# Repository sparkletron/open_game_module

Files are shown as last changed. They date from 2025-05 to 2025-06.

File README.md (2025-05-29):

# Open Game Module
### Schematic, PCB, and CPLD design.



---

  author: Jay Convertino

  date: 2025.05.21

  details: Open Game Module Expansion for the Coleocvision that is Super Game Module compatible.

  license: MIT

---

## LICENSE
  - All files related to or generated from the KiCAD source fall under the MIT license.
  - All files related to or generated from the Verilog source fall under the MIT license.
  - All files generated by me, Jay Convertino, fall under the MIT license.
  - All files from other sources fall under the license of their specification.

## RELEASE VERSIONS
### Current
  - 1.0.0 - First working version

### Past
  - DEV

## Intro
  This is a open source version of the Super Game Module. This uses a CPLD for the glue logic.

## Documentation
  For detailed usage information, please navigate to one of the following sources. They are the same, just in a different format.
  - [open_game_module.pdf](docs/manual/open_game_module.pdf)
  - [github page](https://sparkletron.github.io/open_game_module/)

## SOFTWARE REQUIREMENTS
  - KiCAD v8.X
  - Quartus v13.0.1sp1 web edition
  - Altera USB Blaster

## BUILD TIPS
  This design is made so anyone can build this. Though it will need a board from a PCB manufacture due to the small pitch and
  vias. There are only a few SMD devices, the CPLD, and a few resistors. These are larger to help make soldering easier.

  Recommend populating the SMD parts first, then moving on to the through hole parts from passive to active.

  All case parts are ABS Plastic.

## Completed Project Image

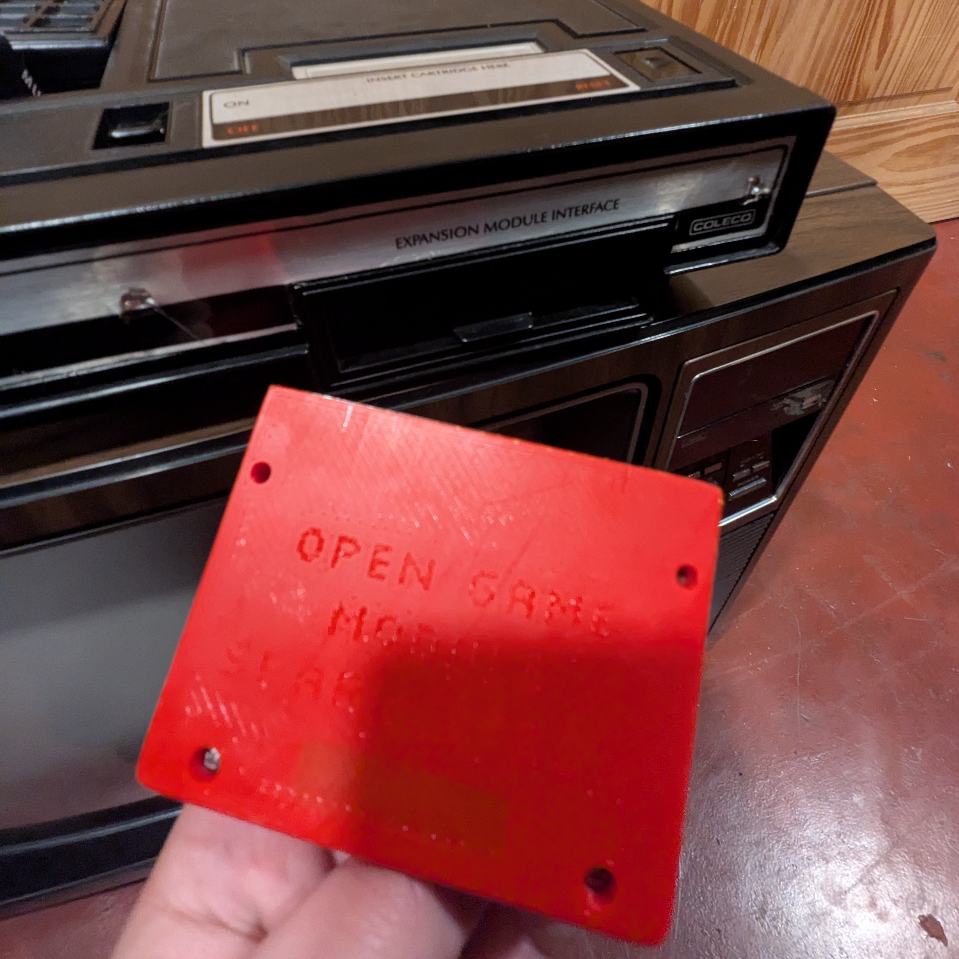
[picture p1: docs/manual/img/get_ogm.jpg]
ogm|300


## PCB IMAGE

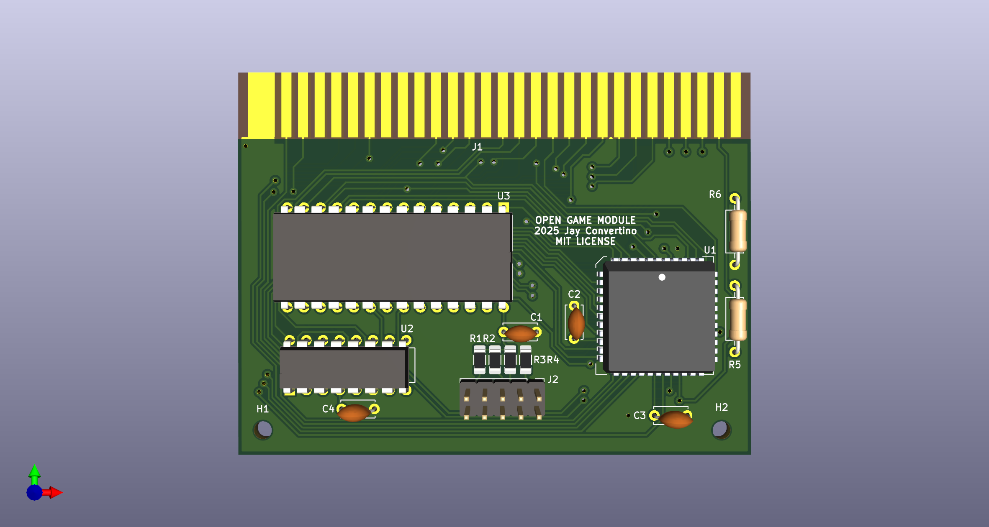
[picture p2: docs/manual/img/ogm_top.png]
pcb_3D_img_front|300


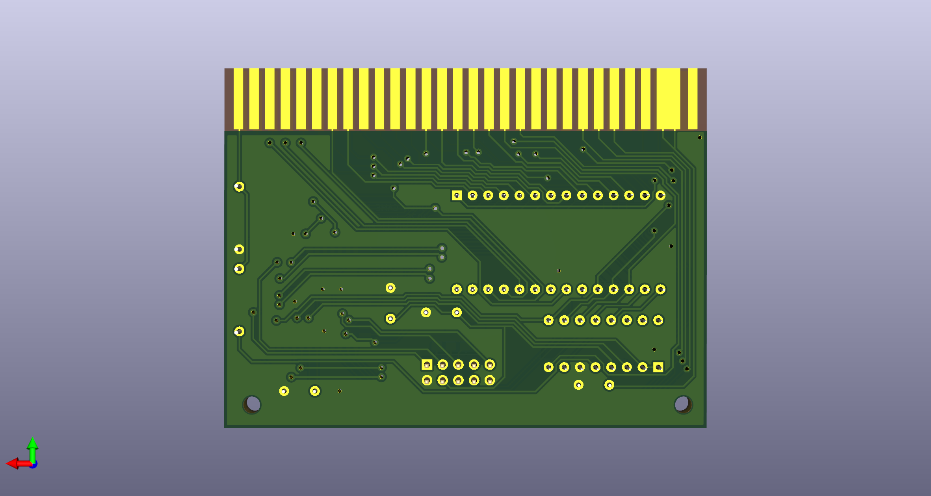
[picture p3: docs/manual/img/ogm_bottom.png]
pcb_3D_img_back|300


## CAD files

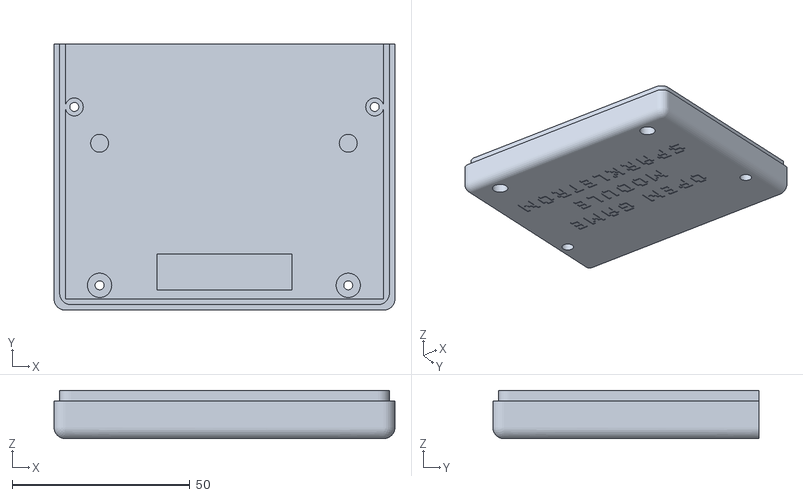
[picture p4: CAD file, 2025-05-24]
models/3D_print/top.stl
96.0 x 75.0 x 13.6

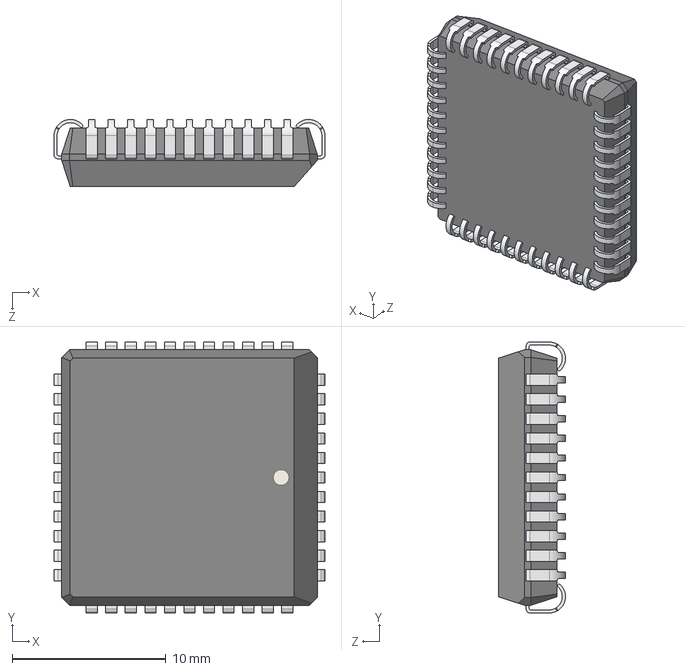
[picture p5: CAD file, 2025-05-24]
schematic/model/User Library-PLCC44-1.STEP
17.6 x 17.6 x 4.36 mm

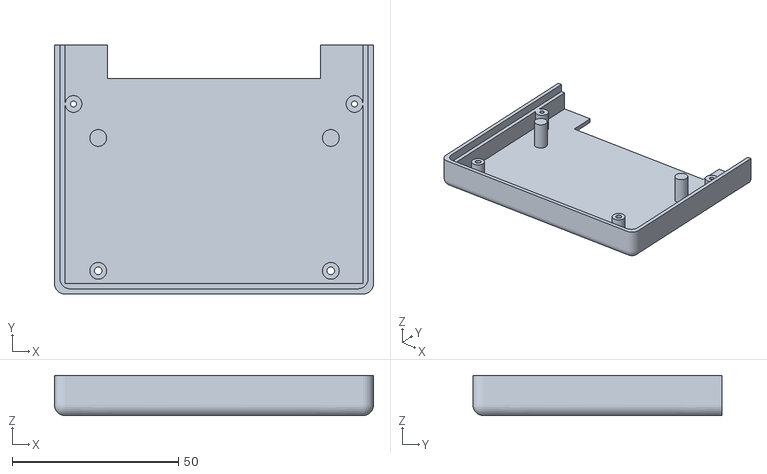
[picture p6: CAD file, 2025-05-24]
models/3D_print/bottom.stl
96.0 x 75.0 x 12.1

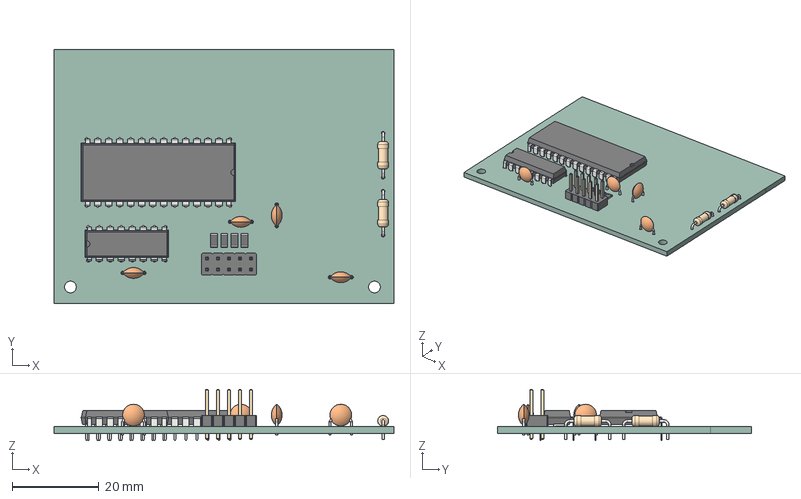
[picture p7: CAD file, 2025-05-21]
schematic/model/open_game_module.step
78.3 x 58.4 x 11.8 mm
PinHeader_2x05_P254mm_Vertical
C_Disc_D50mm_W25mm_P500mm x 4
R_1206_3216Metric x 4
DIP-28_W15.24mm
DIP-16_W7.62mm
R_Axial_DIN0207_L63mm_D25mm_P1016mm_Horizontal x 2
open_game_module_PCB

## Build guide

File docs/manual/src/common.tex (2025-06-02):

\begin{titlepage}
  \begin{center}

  {\Huge Open Game Module}

  \vspace{25mm}

  

  \vspace{25mm}

  \today

  \vspace{15mm}

  {\Large Jay Convertino}

  \end{center}
\end{titlepage}

\tableofcontents

\newpage

\section{Introduction}

\par
Open Game Module (OGM) is a open source expansion card for the Colecovision. This module is Super Game Module (SGM) compatable.
This means all SGM games will run when this module is used with a Colecovision. The sound is expanded with a Yamaha YMZ284
instead of the GI AY chip.

\subsection{Specifications}

\par
\begin{itemize}
  \item 32KiB of RAM
  \item YMZ284 Sound Chip
  \item MAX7000S CPLD (EPM7064SLC)
  \item PCB, two layer
\end{itemize}

\subsection{Parts List}

\subsubsection{electronics}
\begin{footnotesize}
\begin{longtable}{ |*{4}{c|} }
\hline
{Item} & {Qty} & {Reference(s)} & {Value} \\
\hline
{1} & {1} & {J1} & {Connector, 60 pin} \\
\hline
{2} & {4} & {C1, C2, C3, C4} & {100pF} \\
\hline
{3} & {1} & {U1} & {EPM7064SLC-10} \\
\hline
{4} & {1} & {U2} & {YMZ284} \\
\hline
{5} & {1} & {U3} & {HM62256BLP} \\
\hline
{6} & {1} & {R5} & {2k2} \\
\hline
{7} & {1} & {R6} & {4k7} \\
\hline
{8} & {4} & {R1, R2, R3, R4} & {1k} \\
\hline
{9} & {1} & {J2} & {Pin Header, 10 pin} \\
\hline
\end{longtable}
\end{footnotesize}

\subsubsection{hardware}
\begin{footnotesize}
\begin{longtable}{ |*{4}{c|} }
\hline
{Item} & {Qty} & {Reference(s)} & {Value} \\
\hline
{1} & {2} & {S1} & {\#2-32 x 1/4 Fastenal 0148209, screw} \\
\hline
{1} & {2} & {S2} & {\#4-40 x 1/2 Fastenal 0173613, screw} \\
\hline
{2} & {1} & {TOP} & {top.stl 100.00} \\
\hline
{3} & {1} & {BOTTOM} & {bottom.stl 100.00} \\
\hline
\end{longtable}
\end{footnotesize}

\section{Building}

\par
This document assumes some Electrical Engineering knowledge. Building circuits is not
trivial due to the mix of SMD and through hole components. What follow are general
steps to build the OGM.

\begin{itemize}
  \item Create PCB from schematic/gerber/open\_game\_module.zip
  \item Populate PCB
  \item Power up and program CPLD
  \item 3D print case
  \item Assemble OGM circuit board and case.
\end{itemize}

\subsection{Directory Guide}

\par
Below highlights important folders from the root of the OGM.

\begin{enumerate}
  \item \textbf{docs} Contains all documentation related to this project.
    \begin{itemize}
      \item \textbf{datasheets} Contains all datasheets for components.
      \item \textbf{manual} Contains user manual and github page that are generated from the latex sources.
      \item \textbf{schematic} PDF of the KiCAD schematic.
    \end{itemize}
  \item \textbf{schematic} KiCAD v8.X schematic and PCB designs
    \begin{itemize}
      \item \textbf{gerber} Contains gerber files and archives for production.
    \end{itemize}
  \item \textbf{src} CPLD bitstream source
    \begin{itemize}
      \item \textbf{open\_game\_module} Contains verilog source code and constraits
      \item \textbf{quartus13sp01} Quartus project used to generate bitstream. POF file located here.
    \end{itemize}
\end{enumerate}

\subsection{Dependencies}

\par
The following are the dependencies needed to build the bitstream and PCB for the system.

\begin{itemize}
  \item Quartus 13.0 sp1
  \item python 3.X
  \item KiCAD v8.X
\end{itemize}

\input{src/fusesoc/files_fusesoc.tex}

\subsubsection{Fusesoc}
\par
Fusesoc is used for the simulation target only. There are no build targets due to the use of Quartus 13.0sp1.
This makes the use of it a bit silly. It does make it easier to use in future projects where the RAM,ROM,CPU,VDP,
and Sound chips are also IP cores.

\input{src/fusesoc/targets_fusesoc.tex}

\subsubsection{Quartus}
\par
This project uses the last version of Quartus that supports the MAX7000S series. The version is 13.0sp1.
The project is located at src/quartus13sp01/. Once you have the project open please follow the softwares steps
for building and programming the CPLD bitstream.

\subsection{PCB}

\par
The top has all the components of the circuit. The bottom contains none. This is a simple two layer board with a card edge. The card edge must have the pins of the socket bent to make contact and be soldered to it. The right angle connector is double the cost of the vertical one. Plus these are easier to obtain.

\begin{figure}[h!]
\caption{Top}
\centering

\end{figure}

\begin{figure}[h!]
\caption{Bottom}
\centering

\end{figure}

\subsection{3D Printed Case}

\par
The 3D printed case has been tested on two different printers. It has only been tested with ABS filament.
The parts list for the 3D printed case has the STL file name in the value and the XXX.X value is the scale size.
In general I recommend the following steps for assembly.

\begin{enumerate}
  \item Bottom, sit pcb aligned to screw holes.
  \item Top, sit top half on top and install screws.
\end{enumerate}

\subsection{CPLD Programming}

\par
There is one device that need to be programmed which is the CPLD (complex programmable logic device).
This is programmed with quartus using the JTAG header to upload the bitfile.
\par
Quartus 13.0sp1 is the easiest way to build and program the MAX7000 CPLD. You will need an altera blaster.
I recommend the chinese clone blasters, they actually worked the best. While the worst was the Terasic blaster
which did not work at all. As for instructions on how to program it in Quartus, please see the software for details.

\newpage

\section{Usage}

\subsection{Console}
\par
The expansion module must be firmly inserted into the expansion connector of the Colecovision while it is powered off. If you have issues, be sure to clean the Colecovision expansion connector and reinsert the cart. It is recommened to push the cart in as straght as possible.

\begin{enumerate}
  \item \textbf{Get OGM} \par 
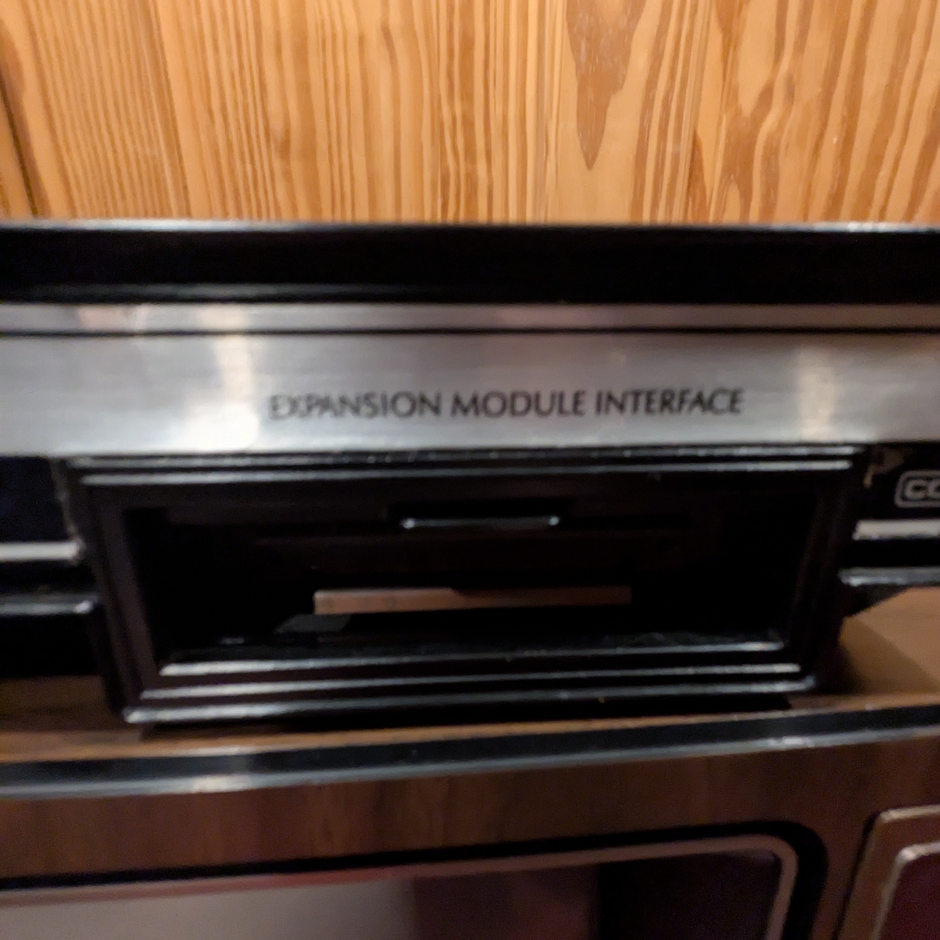
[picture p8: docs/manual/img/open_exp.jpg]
  \item \textbf{Open Expansion Cover} \par 
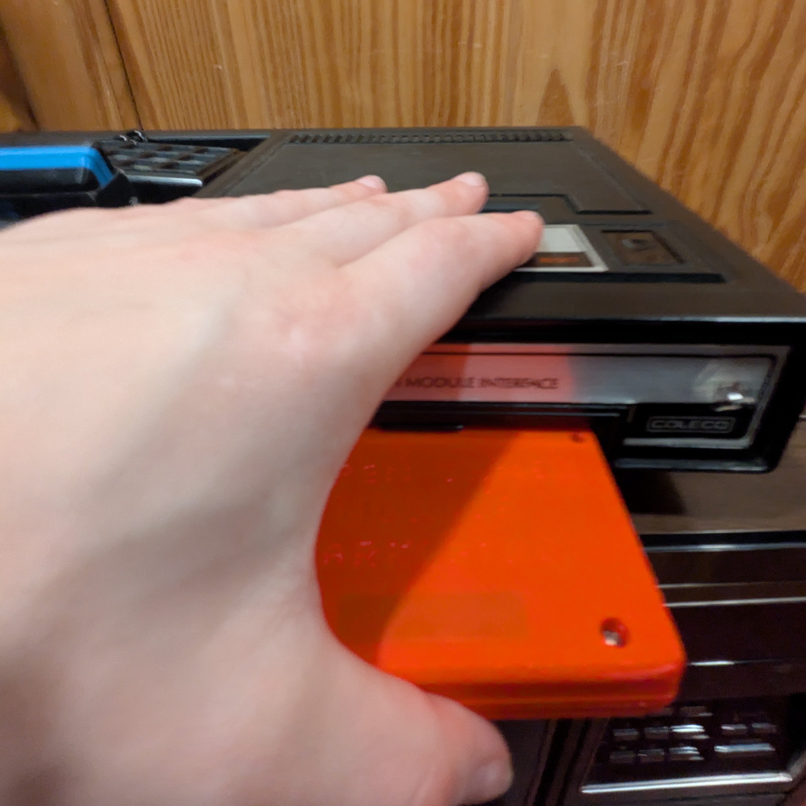
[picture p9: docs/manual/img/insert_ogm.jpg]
  \item \textbf{Insert Open Game Module} \par 
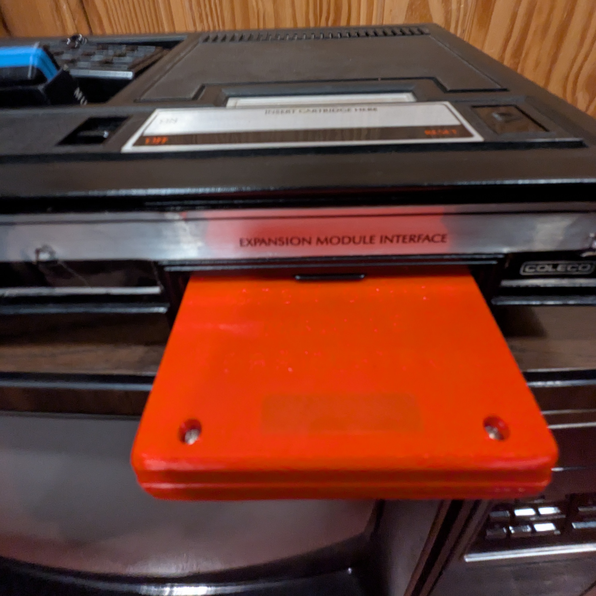
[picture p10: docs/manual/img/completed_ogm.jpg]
  \item \textbf{Completed} \par 
\end{enumerate}

\subsection{Software Programming}
\par
Module Documentation has in\-depth details for using the OGM register bits. You could do this in many different ways, but
having the SDCC compiler know ahead of time that the RAM is there works well for me. There are different stragies that could be done for this
but I feel this is the simplest way. Other methods can provide better detection of the OGM. The psudo code steps are as follows.

\begin{enumerate}
  \item Setup expansion RAM, (NOTE COULD CHECK IF REGISTER VALUE IS EQUAL TO THE DEFAULT TO VERIFY SGM)
  \item Setup IRQS
  \item Copy IRQs to RAM where ROM jumps used to be.
  \item Setup Sound CHIP, (READ BACK TO CHECK EXISTANCE)
\end{enumerate}

\subsubsection{Assembly Code For RAM Init}

\par
This brief assembly code doesn't actually check for the SGM it simply enables the ram registers, sets the irqs, and starts main. This code is taken
from RODAC and isn't complete, see RODAC coleco\_sgm arch crt0.s for complete code.

\begin{lstlisting}[language={[x86masm]Assembler}]
_SGM_RAM_ENA_PORT     .equ 0x0053
_SGM_BIOS_SWAP_PORT   .equ 0x007F
_NMI_SIZE             .equ (_irq_nmi_end - _irq_nmi + 1)
_SPIN_SIZE            .equ (_irq_spin_end - _irq_spin + 1)
;setup for super game module.
ld a,#0x01
out (_SGM_RAM_ENA_PORT), a
ld a,#0x0D
out (_SGM_BIOS_SWAP_PORT), a
;setup ram locations with irq vectors?, 0x8 etc.
;reti
ld a,#0xED
ld (0x08),a
ld (0x10),a
ld (0x18),a
ld (0x20),a
ld (0x28),a
ld (0x30),a
ld a,#0x4D
ld (0x09),a
ld (0x11),a
ld (0x19),a
ld (0x21),a
ld (0x29),a
ld (0x31),a
;copy code to ram
;nmi first
ld bc, #_NMI_SIZE
ld hl, #_irq_nmi
ld de, #0x0066
ldir
;spin
ld bc, #_SPIN_SIZE
ld hl, #_irq_spin
ld de, #0x0038
ldir
ld	sp, #0x8000
call gsinit
call  _main
rst   0x0
\end{lstlisting}

\subsubsection{C Code for SDCC}

\par
The code below is based on using SDCC 4.X.X as the C complier with a custom crt0.s. Essentially for the sound chip you
need to communicate with it by writing an address to it to use, then the data. You can also read from the it to
verify the chip exists and that the OGM is working. Though for the OGM its chip does not have a read function. It is
emulated for registers 0, 2, and 4 (0=1, 2=3, and 4=5) in the CPLD so all opcode/team pixelboy games will startup correctly.

\begin{lstlisting}[language=C]

#define GI_SND_CP_ADDR    0x50
#define GI_SND_WDATA_ADDR 0x51
#define GI_SND_RDATA_ADDR 0x52

__sfr __at(GI_SND_CP_ADDR)    GI_SND_CP_PORT;
__sfr __at(GI_SND_WDATA_ADDR) GI_SND_WDATA_PORT;
__sfr __at(GI_SND_RDATA_ADDR) GI_SND_RDATA_PORT;

/*** send address to chip ***/
inline void sendAddr(uint8_t addr)
{
  di();

  GI_SND_CP_PORT = addr;

  ei();
}

/*** send data to chip ***/
inline void sendData(uint8_t data)
{
  di();

  GI_SND_WDATA_PORT = data;

  ei();
}

/*** send data to chip ***/
inline void readData(uint8_t data)
{
  di();

  data = GI_SND_RDATA_PORT;

  ei();
}
\end{lstlisting}

\section{Architecture}

\par
The OGM architecture emulates the Super Game Module. This is done with a CPLD which performs the RAM (32KiB) and sound (YMZ284) selects. It also caches the the sound writes for later reads. For the RAM selects this is done by emulating the original 74LS138 decoders. This is used to disable the internal RAM with the register at 0x53 by writing one to bit zero. This will remove the internal 1KiB and extend the console to 24KiB. Then to swap out the ROM for RAM for an additional 8KiB the register 0x7F has a zero written to bit one (default value for the register is 0x0F). For the sound, all writes to register 7 and lower have an address cache to store the last address requested. This is due to the architecture of the original chip where the address is selected and then a read is performed. With the address set a subset of the register addresses are mapped to cache registers on the CPLD. See the section after this one for the mapping. This allows the cheaper YMZ284 to be used for sound generation. There are two resistors used to pad the output of the YMZ284 for acceptable levels when mixed with the original in the console. The console internally has a DC blocking capacitor, so no additional capacitors are needed.

\subsection{Fix for opcode games}

Opcode super game module mega cart games have a particular check for the sound chip in there startup routine.

\begin{enumerate}
  \item Set AY register address to 0x00
  \item Write the value 0xAA to AY (register 0x00).
  \item Set AY register address to 0x02
  \item Write the value 0x55 to AY (register 0x02).
  \item Set AY register address to 0x00
  \item Read the value from AY (register 0x00).
  \item Compare to value originally written (0xAA), fail if not matching
  \item Set AY register address to 0x02
  \item Read the value from AY (register 0x02).
  \item Compare to value originally written (0x55), fail if not matching.
\end{enumerate}

The hack fix for my setup is to only have 4 8 bit regiters for 0,1,2,3,4,5,6, and 7. The mapping is
AY Software Register ADDRESS => Cache Register ADDRESS

\begin{itemize}
  \item 0 => 0
  \item 1 => 0
  \item 2 => 1
  \item 3 => 1
  \item 4 => 2
  \item 5 => 2
  \item 6 => 3
  \item 7 => 3
\end{itemize}

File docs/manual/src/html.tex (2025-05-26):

\documentclass{article}
\usepackage{graphicx}
\usepackage{listings}
\usepackage{longtable}
\usepackage[hidelinks]{hyperref}
\begin{document}

  \include{src/common.tex}

  \section{Module Documentation}

  \subsection{\href{../files/open_game_module-v.html}{Open Game Module}}

  \section{Schematics}

  \subsection{\href{../../../schematic/open_game_module.pdf}{Open Game Module}}

\end{document}

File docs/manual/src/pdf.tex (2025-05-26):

\documentclass[usletter]{article}
\usepackage{DejaVuSans}
\renewcommand*\familydefault{\sfdefault}
\usepackage[T1]{fontenc}
\usepackage{graphicx}
\usepackage{listings}
\usepackage{pdfpages}
\usepackage{multirow}
\usepackage{lscape}
\usepackage{graphics}
\usepackage{longtable}
\usepackage{graphics}
\usepackage{lscape}
\usepackage[hidelinks]{hyperref}
\begin{document}

  \include{src/common.tex}

  \section{Code Documentation}
  \par
  This section documents the verilog code for the CPLD in detail.

  \includepdf[pages=-, addtotoc={1,subsection,1,Open Game Module,p1}, pagecommand={}]{open_game_module-v.pdf}

  \section{Drawings and Schematics}
  \par
  This section has CAD drawings and schematics.

  \includepdf[pages=-, addtotoc={1,subsection,1,Schematics,p1}, pagecommand={}]{../schematic/open_game_module.pdf}

\end{document}

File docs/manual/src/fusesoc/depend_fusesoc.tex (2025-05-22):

\subsubsection{Open Game Module Glue Depenecies}
\begin{itemize}
\end{itemize}

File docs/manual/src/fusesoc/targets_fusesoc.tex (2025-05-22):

\subsubsection{Open Game Module Glue Targets}
\begin{itemize}
\item default
	\begin{itemize}
	\item[$\space$] Info: Default IP target for future tool intergration.
	\item src
	\item constr
	\end{itemize}
\item sim
	\begin{itemize}
	\item[$\space$] Info: Simulation target for basic test bench.
	\item src
	\item tb
	\end{itemize}
\end{itemize}

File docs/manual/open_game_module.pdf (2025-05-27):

# Open Game Module

May 27, 2025

## Jay Convertino

## Contents

1 Introduction | 2
2 Building | 2
3 Usage | 7
4 Architecture | 9
5 Code Documentation | 11
6 Drawings and Schematics | 19

1

## 1 Introduction

Open Game Module (OGM) is a open source expansion card for the Colecovision. This module is Super Game Module (SGM) compatable. This means all SGM games will run when this module is used with a Colecovision. The sound is expanded with a Yamaha YMZ284 instead of the GI AY chip.

### 1.1 Specifications

- 32KiB of RAM
- YMZ284 Sound Chip
- MAX7000S CPLD (EPM7064SLC)
- PCB, two layer

### 1.2 Parts List

### 1.2.1 electronics

Item | Qty | Reference(s) | Value
1 | 1 | J1 | Connector, 60 pin
2 | 4 | C1, C2, C3, C4 | 100pF
3 | 1 | U1 | EPM7064SLC-10
4 | 1 | U2 | YMZ284
5 | 1 | U3 | HM62256BLP
6 | 1 | R5 | 470R
7 | 1 | R6 | 4k7
8 | 4 | R1, R2, R3, R4 | 1k
9 | 1 | J2 | Pin Header, 10 pin

### 1.2.2 hardware

Item | Qty | Reference(s) | Value
1 | 4 | S1 | #2-32 x 1/4 Fastenal 0148209, screw
2 | 1 | TOP | top.stl 100.00
3 | 1 | BOTTOM | bottom.stl 100.00

## 2 Building

This document assumes some Electrical Engineering knowledge. Building circuits is not trivial due to the mix of SMD and through hole components. What follow are general steps to build the OGM.

2

- Create PCB from schematic/gerber/open_game_module.zip
- Populate PCB
- Power up and program CPLD
- 3D print case
- Assemble OGM circuit board and case.

### 2.1 Directory Guide

Below highlights important folders from the root of the OGM.

1. docs Contains all documentation related to this project.
- datasheets Contains all datasheets for components.
- manual Contains user manual and github page that are generated from the latex sources.
- schematic PDF of the KiCAD schematic.
2. schematic KiCAD v8.X schematic and PCB designs
- gerber Contains gerber files and archives for production.
3. src CPLD bitstream source
- open_game_module Contains verilog source code and constraits
- quartus13sp01 Quartus project used to generate bitstream. POF file located here.

### 2.2 Dependencies

The following are the dependencies needed to build the bitstream and PCB for the system.

- Quartus 13.0 sp1
- python 3.X
- KiCAD v8.X

3

### 2.2.1 Open Game Module Glue File List

- src

– ’src/open_game_module.v’: ’file_type’: ’verilogSource’

- constr

– ’constr/open_game_module.sdc’: ’file_type’: ’SDC’

- tb

– ’tb/tb_open_game_module.v’: ’file_type’: ’verilogSource’

### 2.2.2 Fusesoc

Fusesoc is used for the simulation target only. There are no build targets due to the use of Quartus 13.0sp1. This makes the use of it a bit silly. It does make it easier to use in future projects where the RAM,ROM,CPU,VDP, and Sound chips are also IP cores.

### 2.2.3 Open Game Module Glue Targets

- default

Info: Default IP target for future tool intergration. – src
– constr
- sim

Info: Simulation target for basic test bench. – src
– tb

### 2.2.4 Quartus

This project uses the last version of Quartus that supports the MAX7000S series. The version is 13.0sp1. The project is located at src/quartus13sp01/. Once you have the project open please follow the softwares steps for building and programming the CPLD bitstream.

### 2.3 PCB

The top has all the components of the circuit. The bottom contains none. This is a simple two layer board with a card edge. The card edge must have the pins of the socket bent to make contact and be soldered to it. The right angle connector is double the cost of the vertical one. Plus these are easier to obtain.

4

Figure 1: Top

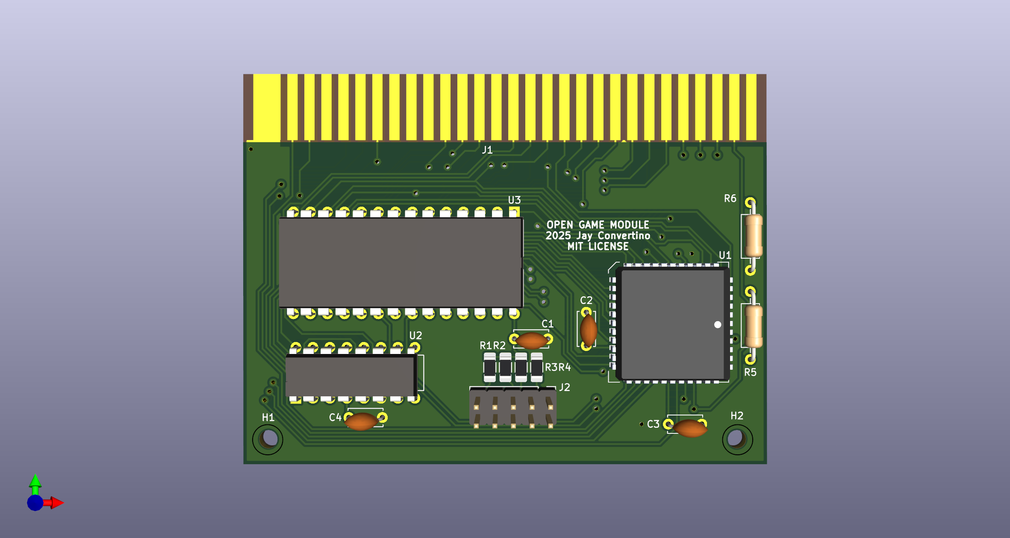
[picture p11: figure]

Figure 2: Bottom


### 2.4 3D Printed Case

The 3D printed case has been tested on two different printers. It has only been tested with ABS filament. The parts list for the 3D printed case has the STL file name in the value and the XXX.X value is the scale size. In general I recommend the following steps for assembly.

1. Bottom, sit pcb aligned to screw holes.
2. Top, sit top half on top and install screws.

5

### 2.5 CPLD Programming

There is one device that need to be programmed which is the CPLD (complex programmable logic device). This is programmed with quartus using the JTAG header to upload the bitfile.
Quartus 13.0sp1 is the easiest way to build and program the MAX7000 CPLD. You will need an altera blaster. I recommend the chinese clone blasters, they actually worked the best. While the worst was the Terasic blaster which did not work at all. As for instructions on how to program it in Quartus, please see the software for details.

6

## 3 Usage

### 3.1 Console

The expansion module must be firmly inserted into the expansion connector of the Colecovision. If you have issues, be sure to clean the connectors.

1. Open Expansion Cover
2. Insert Open Game Module

### 3.2 Software Programming

Module Documentation has indepth details for using the OGM register bits. You could do this in many different ways, but having the SDCC compiler know ahead of time that the RAM is there works well for me. There are different stragies that could be done for this but I feel this is the simplest way. Other methods can provide better detection of the OGM. The psudo code steps are as follows.

1. Setup expansion RAM, (NOTE COULD CHECK IF REGISTER VALUE IS EQUAL TO THE DEFAULT TO VERIFY SGM)
2. Setup IRQS
3. Copy IRQs to RAM where ROM jumps used to be.
4. Setup Sound CHIP, (READ BACK TO CHECK EXISTANCE)

### 3.2.1 Assembly Code For RAM Init

This brief assembly code doesn’t actually check for the SGM it simply enables the ram registers, sets the irqs, and starts main. This code is taken from RODAC and isn’t complete, see RODAC coleco_sgm arch crt0.s for complete code.

_SGM_RAM_ENA_PORT | .equ 0x0053
_SGM_BIOS_SWAP_PORT | .equ 0x007F
_NMI_SIZE | .equ ( _irq_nmi_end − _irq_nmi + 1)
_SPIN_SIZE | .equ ( _irq_spin_end − _irq _spin + 1)
; setup fo r super game module.
ld a,#0x01
out (_SGM_RAM_ENA_PORT) , a
ld a,#0x0D
out (_SGM_BIOS_SWAP_PORT) , a
; setup ram locations with i rq vectors? , 0x8 e tc .
| 7

; r e t i
ld a,#0xED
ld (0x08 ) ,a
ld (0x10 ) ,a
ld (0x18 ) ,a
ld (0x20 ) ,a
ld (0x28 ) ,a
ld (0x30 ) ,a
ld a,#0x4D
ld (0x09 ) ,a
ld (0x11 ) ,a
ld (0x19 ) ,a
ld (0x21 ) ,a
ld (0x29 ) ,a
ld (0x31 ) ,a
; copy code to ram
;nmi f i r s t
ld bc , #_NMI_SIZE
ld hl , #_irq_nmi
ld de , #0x0066
l d i r
; spin
ld bc , #_SPIN_SIZE
ld hl , #_irq _spin
ld de , #0x0038
l d i r
ld | sp, #0x8000
ca l l g sini t
ca l l | _main
r s t | 0x0

### 3.2.2 C Code for SDCC

The code below is based on using SDCC 4.X.X as the C complier with a custom crt0.s. Essentially for the sound chip you need to communicate with it by writing an address to it to use, then the data. You can also read from the it to verify the chip exists and that the OGM is working. Though for the OGM its chip does not have a read function. It is emulated for registers 0, 2, and 4 (0=1, 2=3, and 4=5) in the CPLD so all opcode/team pixelboy games will startup correctly.

#define GI_SND_CP_ADDR 0x50

#define GI_SND_WDATA_ADDR 0x51

#define GI_SND_RDATA_ADDR 0x52

8

_ _ s f r __at (GI_SND_CP_ADDR) GI_SND_CP_PORT ;
_ _ s f r __at (GI_SND_WDATA_ADDR) GI_SND_WDATA_PORT; _ _ s f r __at (GI_SND_RDATA_ADDR) GI_SND_RDATA_PORT ;

/∗∗∗ send address to chip ∗∗∗/
inlin e void sendAddr ( uint8_t addr )
{
di ( ) ;

GI_SND_CP_PORT = addr ;

ei ( ) ;
}

/∗∗∗ send data to chip ∗∗∗/ inlin e void sendData ( uint8_t data ) {
di ( ) ;

GI_SND_WDATA_PORT = data ;

ei ( ) ;
}

/∗∗∗ send data to chip ∗∗∗/ inlin e void readData ( uint8_t data ) {
di ( ) ;

data = GI_SND_RDATA_PORT ;

ei ( ) ;
}

## 4 Architecture

The OGM architecture emulates the Super Game Module. This is done with a CPLD which performs the RAM (32KiB) and sound (YMZ284) selects. It also caches the the sound writes for later reads. For the RAM selects this is done by emulating the original 74LS138 decoders. This is used to disable the internal RAM with the register at 0x53 by writing one to bit zero. This will remove the internal 1KiB and extend the console to 24KiB. Then to swap out the ROM for RAM for an additional 8KiB the register 0x7F has a zero written to bit one (default

9

value for the register is 0x0F). For the sound, all writes to register 7 and lower have an address cache to store the last address requested. This is due to the architecture of the original chip where the address is selected and then a read is performed. With the address set a subset of the register addresses are mapped to cache registers on the CPLD. See the section after this one for the mapping. This allows the cheaper YMZ284 to be used for sound generation. There are two resistors used to pad the output of the YMZ284 for acceptable levels when mixed with the original in the console. The console internally has a DC blocking capacitor, so no additional capacitors are needed.

### 4.1 Fix for opcode games

Opcode super game module mega cart games have a particular check for the sound chip in there startup routine.

1. Set AY register address to 0x00
2. Write the value 0xAA to AY (register 0x00).
3. Set AY register address to 0x02
4. Write the value 0x55 to AY (register 0x02).
5. Set AY register address to 0x00
6. Read the value from AY (register 0x00).
7. Compare to value originally written (0xAA), fail if not matching
8. Set AY register address to 0x02
9. Read the value from AY (register 0x02).
10. Compare to value originally written (0x55), fail if not matching.

The hack fix for my setup is to only have 4 8 bit regiters for 0,1,2,3,4,5,6, and 7. The mapping is AY Software Register ADDRESS => Cache Register ADDRESS

- 0 => 0
- 1 => 0
- 2 => 1
- 3 => 1
- 4 => 2
- 5 => 2
- 6 => 3
- 7 => 3

10

## 5 Code Documentation

This section documents the verilog code for the CPLD in detail.

11

# open_game_module.v

## AUTHORS

## JAY CONVERTINO

## DATES

2025/04/19

## INFORMATION

## Brief

Colecovision Emulation of the Super Game Module using a YMZ284 for audio.

## License MIT

Copyright 2025 Jay Convertino
Permission is hereby granted, free of charge, to any person obtaining a copy of this software and associated documentation files (the "Software"), to deal in the Software without restriction, including without limitation the rights to use, copy, modify, merge, publish, distribute, sublicense, and/or sell copies of the Software, and to permit persons to whom the Software is furnished to do so, subject to the following conditions: The above copyright notice and this permission notice shall be included in all copies or substantial portions of the Software.
THE SOFTWARE IS PROVIDED "AS IS", WITHOUT WARRANTY OF ANY KIND, EXPRESS OR IMPLIED, INCLUDING BUT NOT LIMITED TO THE WARRANTIES OF MERCHANTABILITY, FITNESS FOR A PARTICULAR PURPOSE AND NONINFRINGEMENT. IN NO EVENT SHALL THE AUTHORS OR COPYRIGHT HOLDERS BE LIABLE FOR ANY CLAIM, DAMAGES OR OTHER LIABILITY, WHETHER IN AN ACTION OF CONTRACT, TORT OR OTHERWISE, ARISING FROM, OUT OF OR IN CONNECTION WITH THE SOFTWARE OR THE USE OR OTHER DEALINGS IN THE SOFTWARE.

## open_game_module

module open_game_module (
input
clk,

10:0]
A,
input
MREQn,
input
RFSHn,
input
IORQn,
input
WRn,

12

input
RESETn,
input
RDn,

7:0]
D,
output
RAM_CSn,
output
RAM_OEn,
output
AY_CSn,
output
AY_AS
)

Colecovision Super Game Module Glue Logic
Ports
clk | Clock for all devices in the core

A Address input bus from Z80

MREQn | Z80 memory request input, active low
RFSHn | Refresh request, active low
IORQn | Z80 IO request input, active low
WRn | Z80 Write to bus, active low
RESETn | Input for reset, active low
RDn | Z80 Read from bus, active low

D Z80 8 bit data bus, tristate IN/OUT

RAM_CSn | RAM chip select, active low
RAM_OEn | RAM Ouput enable, active low
RAM_WEn | RAM write enable, active low
AY_CSn | AY sound chip chip select
AY_AS | AY data or register select

## REGISTER INFORMATION

Core has 3 registers at the IO addresses that follow.
SOUND_ADDR_CACHE | h50
SOUND_CACHE | h51
RAM_24K_ENABLE | h53

13

SWAP_BIOS_TO_RAM h7F

## SOUND_ADDR_CACHE

localparam SOUND_ADDR_CACHE = 8'h50

Defines the address of r_snd_addr_cache

Setup an address for cache the sound address so each write will be to a proper address (opcode games need to write multiple and read multiple addresses) The resister is only 4 bits since there are only 16 registers max.

## SOUND_CACHE

localparam SOUND_CACHE = 8'h51

Defines the address of r_snd_cache

Cache Sound Chip as the SGM games read from it (Yamaha chip does not have a read like a GI does).

## RAM_24K_ENABLE

localparam RAM_24K_ENABLE = 8'h53

Defines the address of r_24k_ena

Super Game Module 24K RAM enable using bit 0 (Active High)

## SWAP_BIOS_TO_RAM

localparam SWAP_BIOS_TO_RAM = 8'h7F

14

Defines the address of r_swap_ena

Super Game Module BIOS to RAM swap on bit 1 (Active Low)

## r_snd_addr_cache

reg [ 1:0] r_snd_addr_cache = 0

register for SOUND_ADDR_CACHE See Also: SOUND_ADDR_CACHE

## r_24k_ena

reg [ 7:0] r_24k_ena = 0

register for RAM_24K_ENABLE See Also: RAM_24K_ENABLE

## r_swap_ena

reg [ 7:0] r_swap_ena = 8'h0F

register for 8K RAM/ROM swap See Also: SWAP_BIOS_TO_RAM

## r_snd_cache

reg [ 7:0] r_snd_cache[3:0]

register for SOUND_CACHE See Also: SOUND_CACHE

## ASSIGNMENT INFORMATION

How signals are created

## s_enable

assign s_enable = (
RFSHn &
~
MREQn
)

Decided to keep the same method used internally as the coleco. This emualtes the original ttl chip logic.

## s_y0_seln

15

assign s_y0_seln = ~(

A[9] &
~
A[8]
)

Address h0000, ROM/RAM
s_enable | Enable decoder
A[10:8] | Address lines used for select lines (actually lines A[15:13]).

## s_ram2_csn

assign s_ram2_csn = ~(

A[9] &
A[8]
)

Address h2000, RAM
s_enable | Enable decoder
A[10:8] | Address lines used for select lines (actually lines A[15:13]).

## s_ram1_csn

assign s_ram1_csn = ~(

A[9] &
~
A[8]
)

Address h4000, RAM
s_enable | Enable decoder
A[10:8] | Address lines used for select lines (actually lines A[15:13]).

## s_ram0_csn

assign s_ram0_csn = ~(

A[9] &
A[8]
)

Address h6000, RAM
s_enable | Enable decoder
A[10:8] | Address lines used for select lines (actually lines A[15:13]).

## s_ram_csn

16

assign s_ram_csn = (

(
s_ram0_csn | ~r_24k_ena[0])
)

RAM Chip select when address is requested (active low). When the 24k is not enabled, use internal memory.
(s_y0_seln | r_swap_ena[1]) address range starting at h0000, swap bios/rom bit is enabled (1 is
disabled).
(s_ram1_csn |
~r_24k_ena[0])

address range starting at h4000, 24k enable bit from register.

(s_ram2_csn |
~r_24k_ena[0])

address range starting at h2000, 24k enable bit from register.

(s_ram0_csn |
~r_24k_ena[0])

address range starting at h6000, 24k enable bit from register.

## RAM_OEn

assign RAM_OEn = RDn | s_ram_csn

RAM Output enable when read is requested (active low).
RDn | Z80 read request, active low.
s_ram_csn | See Also: s_ram_csn

## RAM_CSn

assign RAM_CSn = s_ram_csn

RAM Chip Select output assignment. s_ram_csn See Also: s_ram_csn

## DECODER INFORMATION FOR SUPER GAME MODULE

How address decoder is created for Super Game Module, using a YMZ284.
SGM IO REG Clocked IO decoder for Super Game Module.

## AY_AS

assign AY_AS = (
A[7:0]

)

h50 is the address select, when selected its in data mode
A[7:0] | If address matches h50, enable
IORQn | Active IO request, enable
WRn | Z80 write is active, enable

17

## s_ay_sound_csn

match both h50 and h51 by ignoring bit 0. Enable AY sound chip.
A[7:0] | If address matches h50 or h51, enable
IORQn | Active IO request, enable
WRn | Z80 write is active, enable

D

assign D = (
A[7:0]

)

read cached register from previous write (AY emulation), at set address location.
A[7:0] | If address matches h52, enable
IORQn | Active IO request, enable
RDn | Z80 read is active, enable

18

## 6 Drawings and Schematics

This section has CAD drawings and schematics.

19

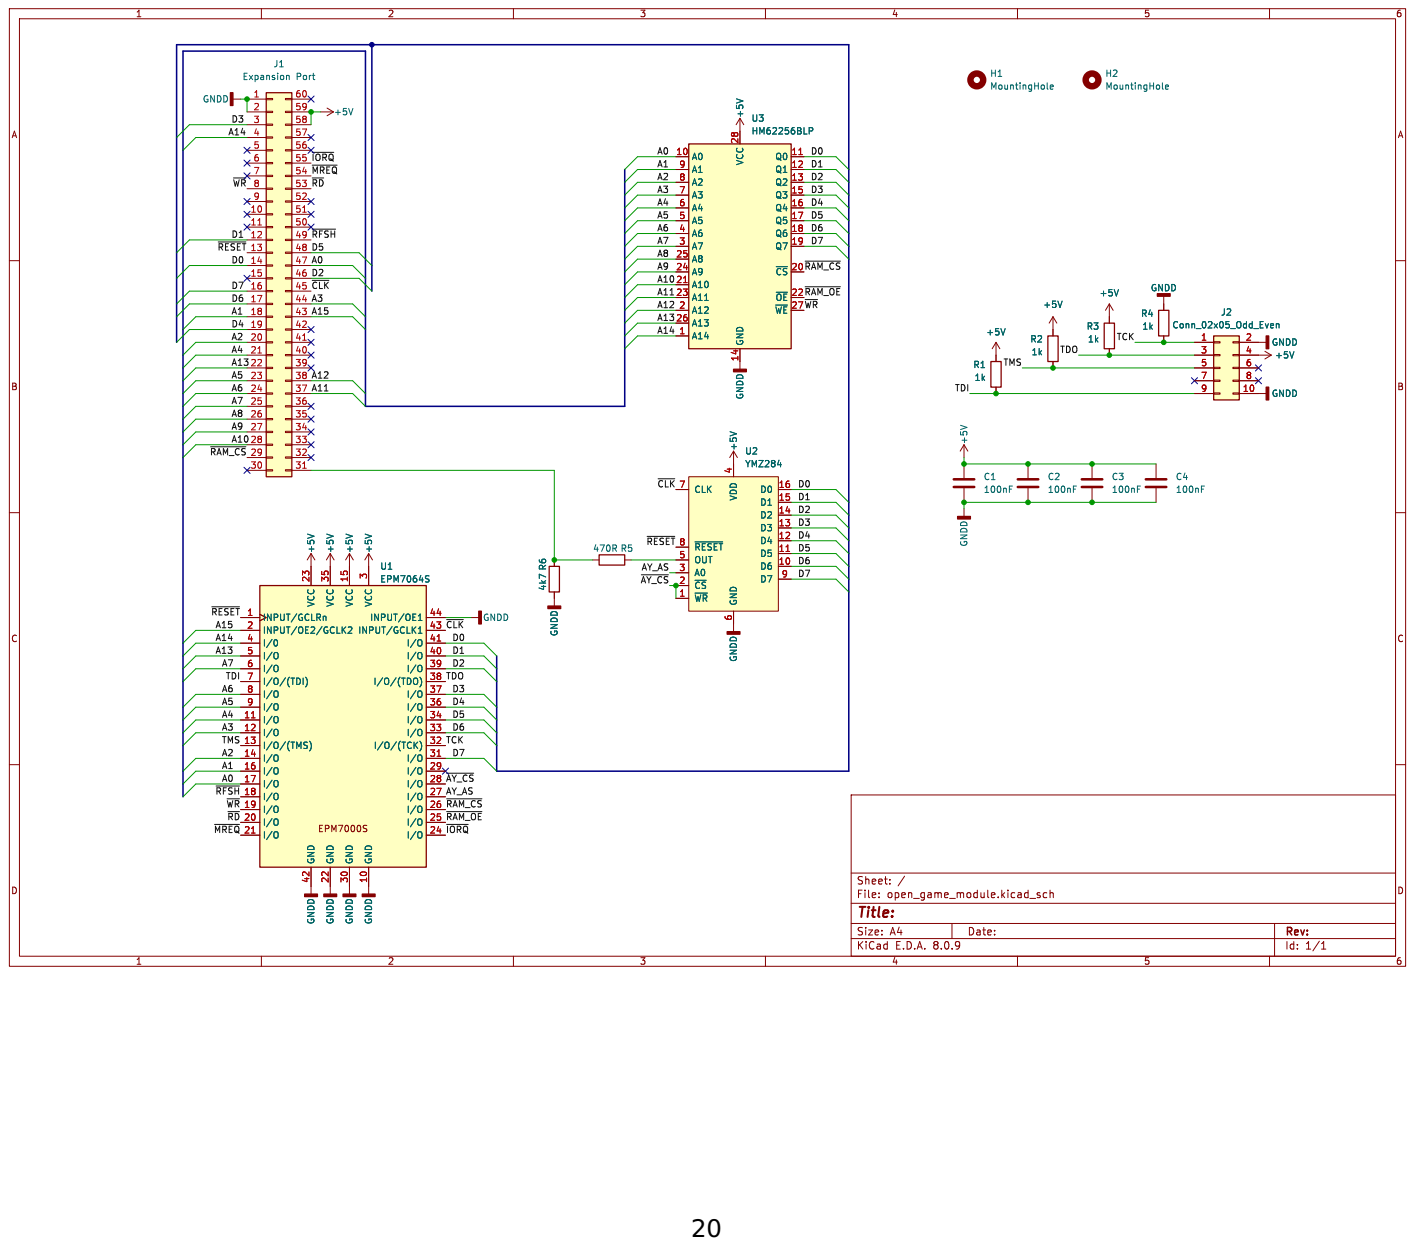
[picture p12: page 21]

6 CLK 7 ~{RESET} 8 D7 9 U2YMZ284 +5V +5V 470R R5 +5V GNDD GNDD GNDD GNDD +5V GNDD GNDD GNDD

6 CLK 7 ~{RESET} 8 D7 9 +5V GNDD R6 4k7 GNDD +5V R1

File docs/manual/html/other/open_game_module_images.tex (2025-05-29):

\batchmode
\documentclass{article}
\RequirePackage{ifthen}

\usepackage{graphicx}
\usepackage{listings}
\usepackage{longtable}
\usepackage[hidelinks]{hyperref}

\usepackage{xcolor}

\makeatletter

\makeatletter
\count@=\the\catcode`\_ \catcode`\_=8 
\newenvironment{tex2html_wrap}{}{}%
\catcode`\<=12\catcode`\_=\count@
\newcommand{\providedcommand}[1]{\expandafter\providecommand\csname #1\endcsname}%
\newcommand{\renewedcommand}[1]{\expandafter\providecommand\csname #1\endcsname{}%
  \expandafter\renewcommand\csname #1\endcsname}%
\newcommand{\newedenvironment}[1]{\newenvironment{#1}{}{}\renewenvironment{#1}}%
\let\newedcommand\renewedcommand
\let\renewedenvironment\newedenvironment
\makeatother
\let\mathon=$
\let\mathoff=$
\ifx\AtBeginDocument\undefined \newcommand{\AtBeginDocument}[1]{}\fi
\newbox\sizebox
\setlength{\hoffset}{0pt}\setlength{\voffset}{0pt}
\addtolength{\textheight}{\footskip}\setlength{\footskip}{0pt}
\addtolength{\textheight}{\topmargin}\setlength{\topmargin}{0pt}
\addtolength{\textheight}{\headheight}\setlength{\headheight}{0pt}
\addtolength{\textheight}{\headsep}\setlength{\headsep}{0pt}
\newwrite\lthtmlwrite
\makeatletter
\let\realnormalsize=\normalsize
\global\topskip=2sp
\def\preveqno{}\let\real@float=\@float \let\realend@float=\end@float
\def\@float{\let\@savefreelist\@freelist\real@float}
\def\liih@math{\ifmmode$\else\bad@math\fi}
\def\end@float{\realend@float\global\let\@freelist\@savefreelist}
\let\real@dbflt=\@dbflt \let\end@dblfloat=\end@float
\let\@largefloatcheck=\relax
\let\if@boxedmulticols=\iftrue
\def\@dbflt{\let\@savefreelist\@freelist\real@dbflt}
\def\adjustnormalsize{\def\normalsize{\mathsurround=0pt \realnormalsize
 \parindent=0pt\abovedisplayskip=0pt\belowdisplayskip=0pt}%
 \def\phantompar{\csname par\endcsname}\normalsize}%
\def\lthtmltypeout#1{{\let\protect\string \immediate\write\lthtmlwrite{#1}}}%
\usepackage[tightpage,active]{preview}
\PreviewBorder=0.5bp
\newbox\lthtmlPageBox
\newdimen\lthtmlCropMarkHeight
\newdimen\lthtmlCropMarkDepth
\long\def\lthtmlTightVBoxA#1{\def\lthtmllabel{#1}
    \setbox\lthtmlPageBox\vbox\bgroup\catcode`\_=8 }%
\long\def\lthtmlTightVBoxZ{\egroup
    \lthtmlCropMarkHeight=\ht\lthtmlPageBox \advance \lthtmlCropMarkHeight 6pt
    \lthtmlCropMarkDepth=\dp\lthtmlPageBox
    \lthtmltypeout{^^J:\lthtmllabel:lthtmlCropMarkHeight:=\the\lthtmlCropMarkHeight}%
    \lthtmltypeout{^^J:\lthtmllabel:lthtmlCropMarkDepth:=\the\lthtmlCropMarkDepth:1ex:=\the \dimexpr 1ex}%
    \begin{preview}\copy\lthtmlPageBox\end{preview}}%
\long\def\lthtmlTightFBoxA#1{\def\lthtmllabel{#1}%
    \adjustnormalsize\setbox\lthtmlPageBox=\vbox\bgroup\hbox\bgroup %
    \let\ifinner=\iffalse \let\)\liih@math %
    \bgroup\catcode`\_=8 }%
\long\def\lthtmlTightFBoxZ{\egroup\egroup
    \@next\next\@currlist{}{\def\next{\voidb@x}}%
    \expandafter\box\next\egroup %
    \lthtmlCropMarkHeight=\ht\lthtmlPageBox \advance \lthtmlCropMarkHeight 6pt
    \lthtmlCropMarkDepth=\dp\lthtmlPageBox
    \lthtmltypeout{^^J:\lthtmllabel:lthtmlCropMarkHeight:=\the\lthtmlCropMarkHeight}%
    \lthtmltypeout{^^J:\lthtmllabel:lthtmlCropMarkDepth:=\the\lthtmlCropMarkDepth:1ex:=\the \dimexpr 1ex}%
    \begin{preview}\copy\lthtmlPageBox\end{preview}}%
    \long\def\lthtmlinlinemathA#1#2\lthtmlindisplaymathZ{\lthtmlTightVBoxA{#1}{\hbox\bgroup#2\egroup}\lthtmlTightVBoxZ}
    \def\lthtmlinlineA#1#2\lthtmlinlineZ{\lthtmlTightVBoxA{#1}{\hbox\bgroup#2\egroup}\lthtmlTightVBoxZ}
    \long\def\lthtmldisplayA#1#2\lthtmldisplayZ{\lthtmlTightVBoxA{#1}{#2}\lthtmlTightVBoxZ}
    \long\def\lthtmldisplayB#1#2\lthtmldisplayZ{\\edef\preveqno{(\theequation)}%
        \lthtmlTightVBoxA{#1}{\let\@eqnnum\relax#2}\lthtmlTightVBoxZ}
    \long\def\lthtmlfigureA#1{\let\@savefreelist\@freelist
        \lthtmlTightFBoxA{#1}}
    \long\def\lthtmlfigureZ{
        \lthtmlTightFBoxZ\global\let\@freelist\@savefreelist}
    \long\def\lthtmlpictureA#1{\let\@savefreelist\@freelist
        \lthtmlTightVBoxA{#1}}
    \long\def\lthtmlpictureZ{
        \lthtmlTightVBoxZ\global\let\@freelist\@savefreelist}
\def\lthtmlcheckvsize{\ifdim\ht\sizebox<\vsize 
  \ifdim\wd\sizebox<\hsize\expandafter\hfill\fi \expandafter\vfill
  \else\expandafter\vss\fi}%
\providecommand{\selectlanguage}[1]{}%
\makeatletter \tracingstats = 1 

\begin{document}
\pagestyle{empty}\thispagestyle{empty}\lthtmltypeout{}%
\lthtmltypeout{latex2htmlLength hsize=\the\hsize}\lthtmltypeout{}%
\lthtmltypeout{latex2htmlLength vsize=\the\vsize}\lthtmltypeout{}%
\lthtmltypeout{latex2htmlLength hoffset=\the\hoffset}\lthtmltypeout{}%
\lthtmltypeout{latex2htmlLength voffset=\the\voffset}\lthtmltypeout{}%
\lthtmltypeout{latex2htmlLength topmargin=\the\topmargin}\lthtmltypeout{}%
\lthtmltypeout{latex2htmlLength topskip=\the\topskip}\lthtmltypeout{}%
\lthtmltypeout{latex2htmlLength headheight=\the\headheight}\lthtmltypeout{}%
\lthtmltypeout{latex2htmlLength headsep=\the\headsep}\lthtmltypeout{}%
\lthtmltypeout{latex2htmlLength parskip=\the\parskip}\lthtmltypeout{}%
\lthtmltypeout{latex2htmlLength oddsidemargin=\the\oddsidemargin}\lthtmltypeout{}%
\makeatletter
\if@twoside\lthtmltypeout{latex2htmlLength evensidemargin=\the\evensidemargin}%
\else\lthtmltypeout{latex2htmlLength evensidemargin=\the\oddsidemargin}\fi%
\lthtmltypeout{}%
\makeatother
\setcounter{page}{1}
\onecolumn

% !!! IMAGES START HERE !!!

{\newpage\clearpage
\lthtmlpictureA{tex2html_wrap361}%
%
\lthtmlpictureZ
\lthtmlcheckvsize\clearpage}

\stepcounter{section}
\stepcounter{subsection}
\stepcounter{subsection}
\stepcounter{subsubsection}
\stepcounter{subsubsection}
\stepcounter{section}
\stepcounter{subsection}
\stepcounter{subsection}
\stepcounter{subsubsection}
\stepcounter{subsubsection}
\stepcounter{subsubsection}
{\newpage\clearpage
\lthtmlinlinemathA{tex2html_wrap_inline197}%
$\ $%
\lthtmlindisplaymathZ
\lthtmlcheckvsize\clearpage}

\stepcounter{subsubsection}
\stepcounter{subsection}
{\newpage\clearpage
\lthtmlpictureA{tex2html_wrap462}%
%
\lthtmlpictureZ
\lthtmlcheckvsize\clearpage}

{\newpage\clearpage
\lthtmlpictureA{tex2html_wrap466}%
%
\lthtmlpictureZ
\lthtmlcheckvsize\clearpage}

\stepcounter{subsection}
\stepcounter{subsection}
\stepcounter{section}
\stepcounter{subsection}
{\newpage\clearpage
\lthtmlpictureA{tex2html_wrap471}%
%
\lthtmlpictureZ
\lthtmlcheckvsize\clearpage}

{\newpage\clearpage
\lthtmlpictureA{tex2html_wrap472}%
%
\lthtmlpictureZ
\lthtmlcheckvsize\clearpage}

{\newpage\clearpage
\lthtmlpictureA{tex2html_wrap473}%
%
\lthtmlpictureZ
\lthtmlcheckvsize\clearpage}

{\newpage\clearpage
\lthtmlpictureA{tex2html_wrap474}%
%
\lthtmlpictureZ
\lthtmlcheckvsize\clearpage}

\stepcounter{subsection}
\stepcounter{subsubsection}
\stepcounter{subsubsection}
\stepcounter{section}
\stepcounter{subsection}
\stepcounter{section}
\stepcounter{subsection}
\stepcounter{section}
\stepcounter{subsection}

\end{document}

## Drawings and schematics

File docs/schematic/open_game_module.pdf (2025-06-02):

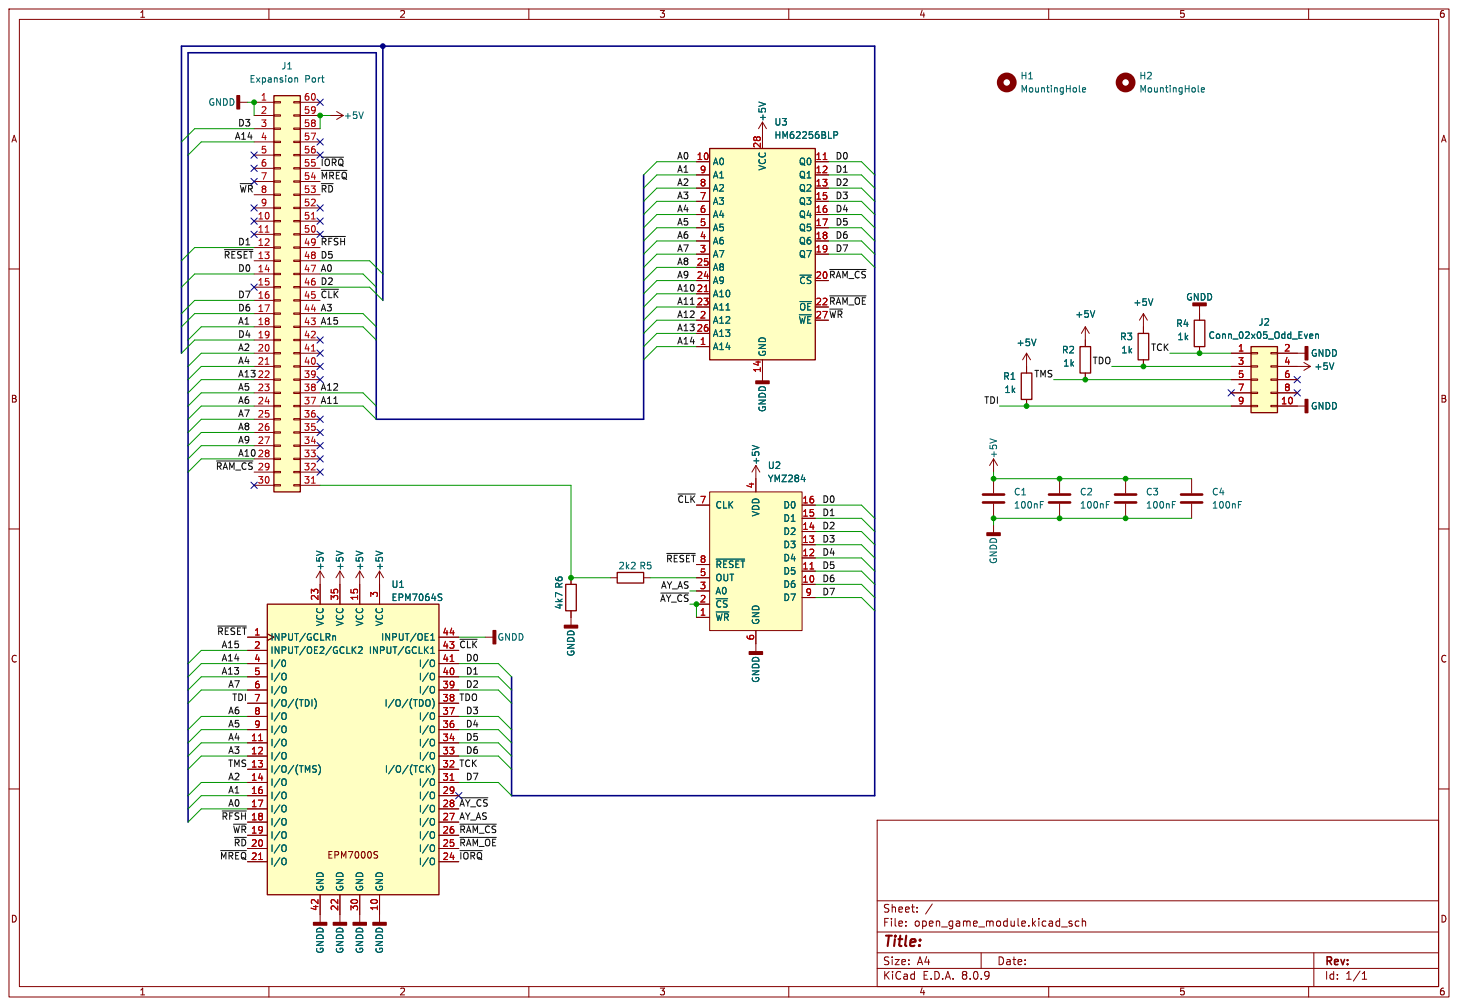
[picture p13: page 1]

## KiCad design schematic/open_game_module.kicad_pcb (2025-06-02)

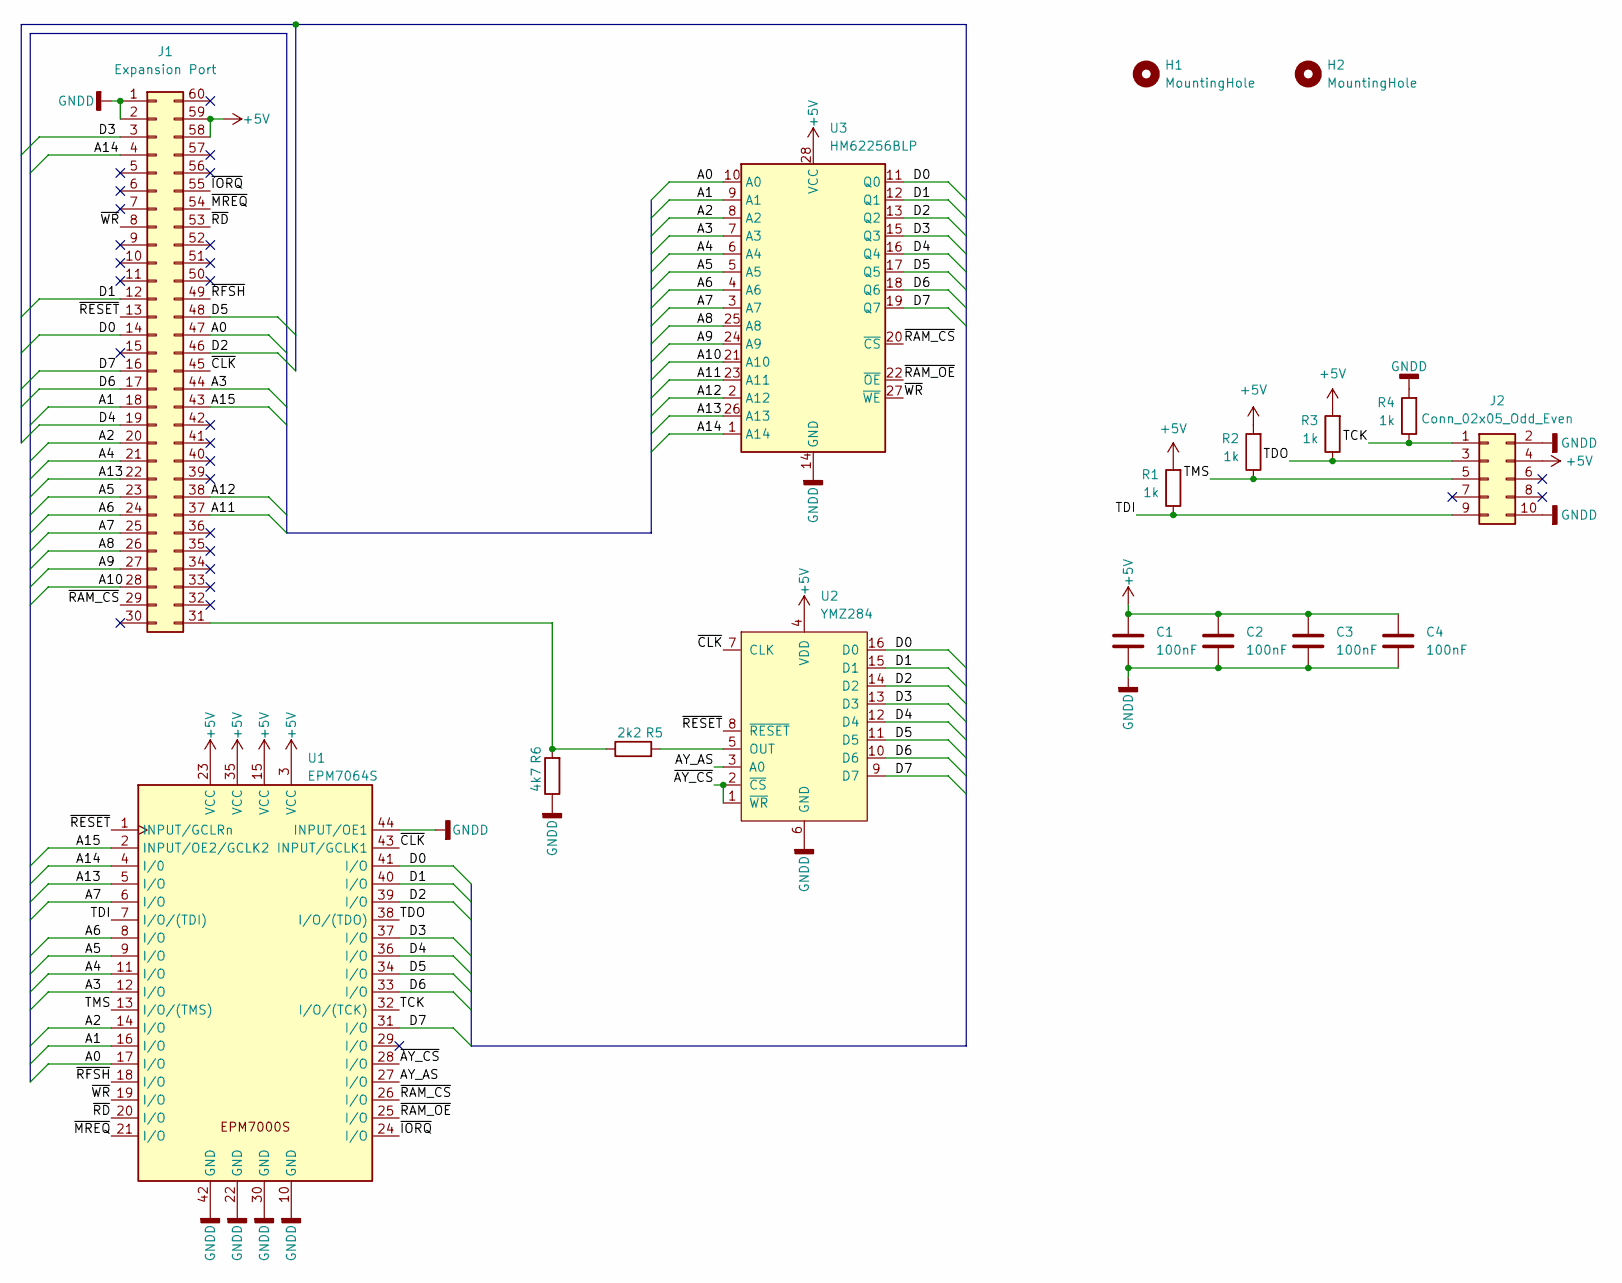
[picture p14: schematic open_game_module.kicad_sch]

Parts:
C1, C2, C3, C4: 100nF; C_Disc_D5.0mm_W2.5mm_P5.00mm
H1, H2: MountingHole; MountingHole_2.7mm_M2.5_ISO14580
J1: Expansion Port; Colecovision_Expansion_Mate
J2: Conn_02x05_Odd_Even; PinHeader_2x05_P2.54mm_Vertical
R1, R2, R3, R4: 1k; R_1206_3216Metric_Pad1.30x1.75mm_HandSolder
R5: 2k2; R_Axial_DIN0207_L6.3mm_D2.5mm_P10.16mm_Horizontal
R6: 4k7; R_Axial_DIN0207_L6.3mm_D2.5mm_P10.16mm_Horizontal
U1: EPM7064S; PLCC-44
U2: YMZ284; DIP-16_W7.62mm
U3: HM62256BLP; DIP-28_W15.24mm

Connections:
+5V: C1.1, C2.1, C3.1, C4.1, J1.58, J1.59, J2.4, R1.2, R2.2, R3.2, U1.3 (VCC), U1.15 (VCC), U1.23 (VCC), U1.35 (VCC), U2.4 (VDD), U3.28 (VCC)
/A0: J1.47, U1.17 (I/O), U3.10 (A0)
/A1: J1.18, U1.16 (I/O), U3.9 (A1)
/A2: J1.20, U1.14 (I/O), U3.8 (A2)
/A3: J1.44, U1.12 (I/O), U3.7 (A3)
/A4: J1.21, U1.11 (I/O), U3.6 (A4)
/A5: J1.23, U1.9 (I/O), U3.5 (A5)
/A6: J1.24, U1.8 (I/O), U3.4 (A6)
/A7: J1.25, U1.6 (I/O), U3.3 (A7)
/A8: J1.26, U3.25 (A8)
/A9: J1.27, U3.24 (A9)
/A10: J1.28, U3.21 (A10)
/A11: J1.37, U3.23 (A11)
/A12: J1.38, U3.2 (A12)
/A13: J1.22, U1.5 (I/O), U3.26 (A13)
/A14: J1.4, U1.4 (I/0), U3.1 (A14)
/A15: J1.43, U1.2 (INPUT/OE2/GCLK2)
/AY_AS: U1.27 (I/O), U2.3 (A0)
/D0: J1.14, U1.41 (I/O), U2.16 (D0), U3.11 (Q0)
/D1: J1.12, U1.40 (I/O), U2.15 (D1), U3.12 (Q1)
/D2: J1.46, U1.39 (I/O), U2.14 (D2), U3.13 (Q2)
/D3: J1.3, U1.37 (I/O), U2.13 (D3), U3.15 (Q3)
/D4: J1.19, U1.36 (I/O), U2.12 (D4), U3.16 (Q4)
/D5: J1.48, U1.34 (I/O), U2.11 (D5), U3.17 (Q5)
/D6: J1.17, U1.33 (I/O), U2.10 (D6), U3.18 (Q6)
/D7: J1.16, U1.31 (I/O), U2.9 (D7), U3.19 (Q7)
/TCK: J2.1, R4.1, U1.32 (I/O/(TCK))
/TDI: J2.9, R1.1, U1.7 (I/O/(TDI))
/TDO: J2.3, R3.1, U1.38 (I/O/(TDO))
/TMS: J2.5, R2.1, U1.13 (I/O/(TMS))
/~AY_CS: U1.28 (I/O), U2.1 (~WR), U2.2 (~CS)
/~CLK: J1.45, U1.43 (INPUT/GCLK1), U2.7 (CLK)
/~IORQ: J1.55, U1.24 (I/O)
/~MREQ: J1.54, U1.21 (I/O)
/~RAM_CS: J1.29, U1.26 (I/O), U3.20 (~CS)
/~RAM_OE: U1.25 (I/O), U3.22 (~OE)
/~RD: J1.53, U1.20 (I/O)
/~RESET: J1.13, U1.1 (INPUT/GCLRn), U2.8 (~RESET)
/~RFSH: J1.49, U1.18 (I/O)
/~WR: J1.8, U1.19 (I/O), U3.27 (~WE)
GNDD: C1.2, C2.2, C3.2, C4.2, J1.1, J1.2, J2.2, J2.10, R4.2, R6.1, U1.10 (GND), U1.22 (GND), U1.30 (GND), U1.42 (GND), U1.44 (INPUT/OE1), U2.6 (GND), U3.14 (GND)
unnamed: J1.31, R5.1, R6.2
unnamed: R5.2, U2.5 (OUT)

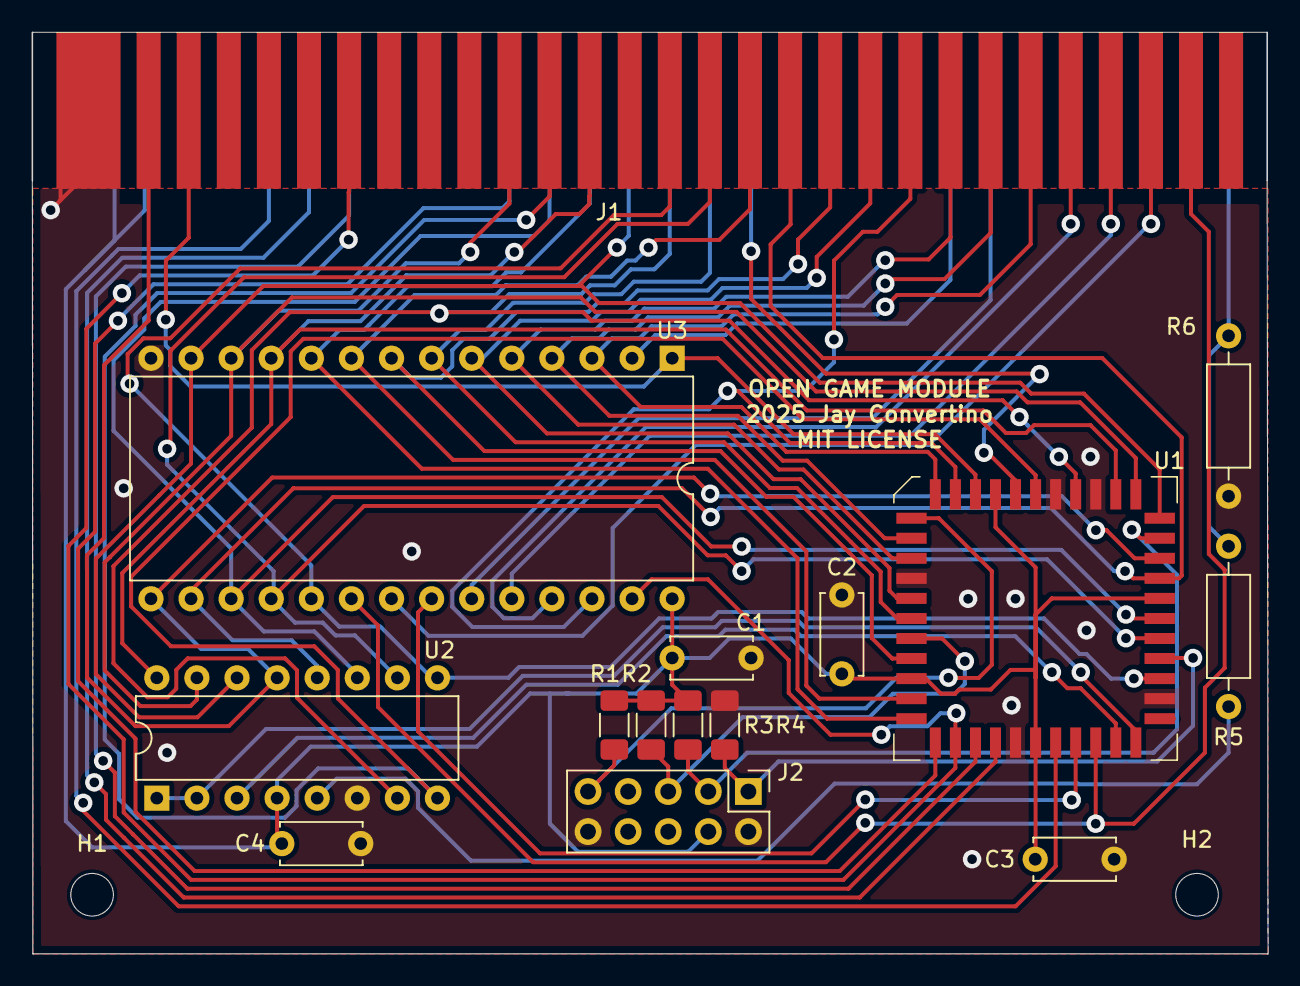
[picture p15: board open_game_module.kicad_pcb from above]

Board: 2 copper layers, 78.3 x 58.4 mm, 17 parts (0 on the bottom side), 43 nets.

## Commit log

2025-04-20 initial commit, docs incorrect
    [open_game_module-B_Cu.gbr, open_game_module-B_Mask.gbr, open_game_module-B_Paste.gbr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]
2025-05-21 added models and pof from quartus
    [bottom.stl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]
2025-05-22 first initial commit thats actually a draft.. at best:
    [open_game_module-B_Cu.gbr, open_game_module-B_Mask.gbr, open_game_module-B_Paste.gbr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]
2025-05-22 update pcb names
2025-05-24 update docs and 3D model of board
    [User Library-PLCC44-1.STEP, open_game_module.kicad_pcb]
2025-05-24 update 3D case models to be a bit smaller height wise, and emboss OGM SPARKLETRON
    [bottom.stl, top.stl]
2025-05-29 update parts listing for new screws
2025-05-29 fixed chip direction
    [open_game_module.kicad_pcb]
2025-05-30 extra model
    [open_game_module.step]
2025-06-02 fix resistor for output to 2k2 due to internal sound chip conflict issue
    [open_game_module-B_Cu.gbr, open_game_module-B_Mask.gbr, open_game_module-B_Paste.gbr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]
